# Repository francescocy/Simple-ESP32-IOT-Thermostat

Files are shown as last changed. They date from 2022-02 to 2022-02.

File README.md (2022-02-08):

# Simple-ESP32-IOT-Thermostat

DISCLAIMER - This project was originally developed in Italian, I'll try to translate as much of it as possible in English; code and comments are English-only already.

PLEASE USE THE LATEST VERSION OF THE .ino FILE! New features and bugfixes are listed as comments at the beggining of each .ino file.

INTRODUCTION

This project was born out of a simple idea: replacing our old and clunky living room thermostat with a modern IOT one, while keeping it simple, DIY and fully open-source. I didn't want to rely on a home assistant or a dodgy app-controlled pre-built thermostat, as they tend to have inexistent long-term support and come with too many options.

DEVELOPMENT CHOICES

Main objective is to end up with an extremely simple LCD interface in the living room, with remote control possible using an HTML page.
The unit must fit within the original thermostat's volume and mimick its look; a 3D printed faceplate will be designed for this.
The LCD must show and allow editing of all key paramenters (set temperature, current temperature, furnace status...)
Advanced options can be added later and will be controlled through HTML.

HARDWARE:

NodeMCU-32s

Dallas DS18B20 digital temperature sensor

ST7735 SPI LCD 1.8" 128x160 pixel

10A 220V relay, with optocoupler, 5V powered, 3.3V and 5V signal input

HiLink HLK-PM01 Step-Down module, isolated 220V AC -> 5V DC 0.6A

SOFTWARE:

Developed with Arduino IDE 1.8.19

Included libraries: WiFi.h; AsyncTCP.h; ESPAsyncWebServer.h; Wire.h; OneWire.h; DallasTemperature.h; AsyncElegantOTA.h; Arduino_GFX_Library.h

OTA update: https://github.com/ayushsharma82/ElegantOTA

HOW TO USE:

Open the .ino file with Arduino IDE or Atom, edit it to suit your WiFi settings, Board, LCD type/size/rotation, pinout etc... Compile it and upload it!
I hope I'll have time to upload a more extensive guide soon.

Bonus: You can try the pre-compiled .bin file to test the code, but it may not play well with different ESP boards and LCDs/OLEDs; starting from V 1.2.5 you can create a temporary guest wifi network from your router using the baked-in wifi credentials SSID="wifi" PASSWORD="password" (intended for testing only, please download the .ino file, compile it locally with your own wifi credentials and upload it to your esp32).

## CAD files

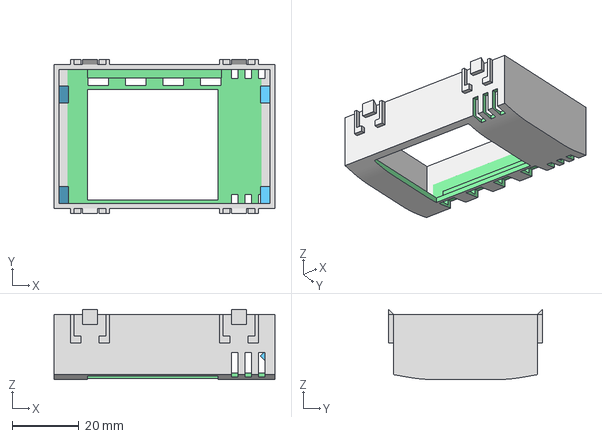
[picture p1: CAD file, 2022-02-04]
Printable 3D faceplate.3mf
66.0 x 46.0 x 21.0 mm

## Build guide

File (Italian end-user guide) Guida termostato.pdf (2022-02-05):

### http://termostato/

SCHEMA DISPLAY TERMOSTATO | PAGINA RAGGIUNGIBILE SULLA LAN O VIA VPN

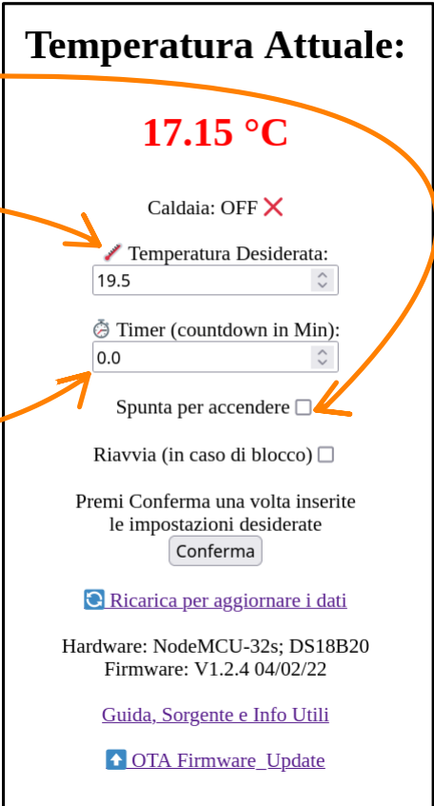
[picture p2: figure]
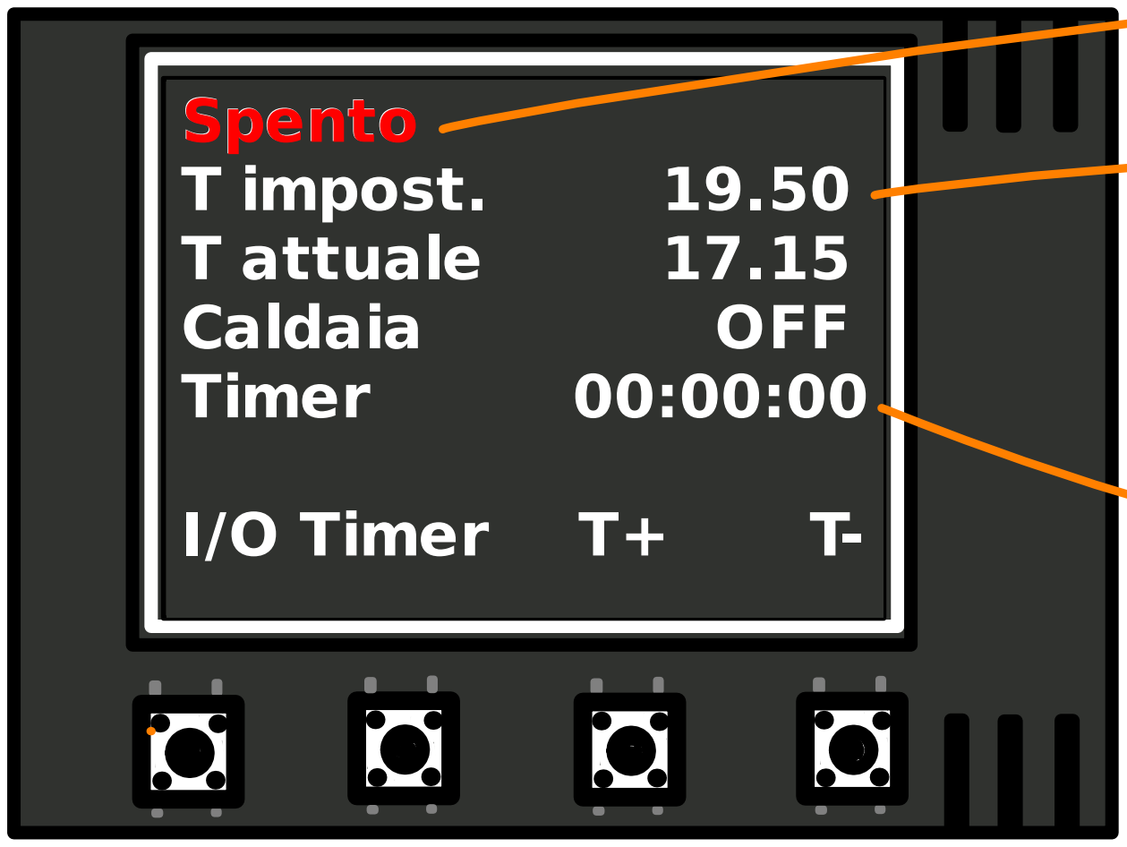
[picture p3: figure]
Spento; T impost.; T attuale; Caldaia; OFF; Timer; I/O Timer

I/O | -> (abilita/disabilita termostato); disabilita il termostato
senza cancellare temperatura e timer attualmente impostati se è già attivo, oppure lo riattiva se non lo è. Una volta attivato, il termostato cercherà di mantenere la temperatura desiderata.

Timer -> Aumenta il contatore di 30' fino a 360 (6h), superate le 6h tornerà a 0 (per impostare tempi più lunghi, usare la pagina HTML). Se il termostato è disabilitato, viene abilitato automaticamente all'inserimento del Timer. Alla fine del countdown, il termostato si disabilita.

T+ | -> Aumenta la temperatura di 0.5⁰C | (fino a un Max di 30⁰C)
T- | -> Riduce la temperatura di 0.5⁰C | (fino a un min di 5⁰C)

INFORMAZIONI UTILI

- Il termostato ha un'isteresi di 0.25⁰C; quando si imposta la temperatura desiderata, la caldaia verrà:
accesa solo se | T Attuale < T Impostata - 0.25⁰C
spenta quando | T Attuale > T Impostata + 0.25⁰C
- La pagina HTML raggiungibile a http://termostato/ è raggiungibile anche all'indirizzo IP (si trova facilmente dalla pagina di management del router della rete di casa)
- I dati presenti sul display sono sempre aggiornati con quelli inviati dall'interfaccia HTML, ma la pagina non si aggiorna automaticamente! Per inviare le impostazioni da remoto, premere il pulsante "Conferma"; per conoscere lo stato attuale del termostato, premere "ricarica per aggiornare i dati"
- In caso di black out, il termostato si riavvierà e tenterà di collegarsi al WiFi automaticamente.
Le impostazioni di default saranno ripristinate: Abilitato in mod. invernale su 15⁰C.
- Se il display non dovesse rispondere/il termostato dovesse comportarsi in maniera erratica, è possibile forzare un riavvio tenendo premuti i tasti I/O + Timer, oppure spuntando l'opportuna casella dalla pagina HTML e poi "Conferma"

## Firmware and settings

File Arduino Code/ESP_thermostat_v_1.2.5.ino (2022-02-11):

/*
 * New in release 1.2.5:
 * Resolved a bug causing the thermostat not to enable when timer is programmed via html
 * Reset timer when user presses I/O button or un-checks field in html page to disable
 * Re-draw menu when pressing I/O or T+ & T- at the same time (useful if stray characters have been printed)
 * menu item drawing moved to "drawMenu" function
 */

#include <WiFi.h>
#include <AsyncTCP.h>
#include <ESPAsyncWebServer.h>
#include <Wire.h>
#include <OneWire.h>
#include <DallasTemperature.h>
#include <AsyncElegantOTA.h>; //this enables OTA updates at IP/update

//setting up GFX for TFT Display starts here
#include <Arduino_GFX_Library.h>
#include "FreeMono8pt7b.h"

/* More dev device declaration: https://github.com/moononournation/Arduino_GFX/wiki/Dev-Device-Declaration */
#if defined(DISPLAY_DEV_KIT)
Arduino_GFX *gfx = create_default_Arduino_GFX();
#else /* !defined(DISPLAY_DEV_KIT) */

/* More data bus class: https://github.com/moononournation/Arduino_GFX/wiki/Data-Bus-Class */
Arduino_DataBus *bus = create_default_Arduino_DataBus();

/* More display class: https://github.com/moononournation/Arduino_GFX/wiki/Display-Class */
Arduino_GFX *gfx = new Arduino_ST7735(bus, TFT_RST, 1 /* rotation */, false /* IPS */);

#endif /* !defined(DISPLAY_DEV_KIT) */
/*******************************************************************************
 * End of Arduino_GFX setting
 ******************************************************************************/
const float tscale = 0.88; /*time scaling to adjust for clock inaccuracy; won't be perfect,
but saves us from using NTP or an RTC (lower values make the timer run faster)*/
float   timer = 0;  //time in min
float   tcnt = 0;   //actual time counter
int     hrrem = 0;  //H remaining
int     minrem = 0; //Min remaining
int     secrem = 0; //Sec remaining
#define  maxtemp 30 //Max allowed temperature in input field
#define  mintemp 5  //min allowed temperature in input field
float   settemp = 15;
#define temp_offset -3.6 //sensor offset in Celsius

// PWM or DAC specs for BL control
#define TFT_BL     25
#define maxdutycycle 255
#define mindutycycle 210
#define BL_cntDownMax 50
int     dutycycle = 255;
int     BTN_Press = 0;
int     BL_cntDown = BL_cntDownMax;

//Hardware Buttons
int del = 0; //general delay to run at beginning of loop
#define btndelays 2 //avoids double press
#define btndelayl 10 //delay for longer operations, like resetting timer
#define BTN1      13 //on/off
#define BTN2      14 //timer
#define BTN3      16 //temp +
#define BTN4      17 //temp -

const char* ssid = "MINOU";   //replace with your SSID
const char* password = "thispasswordissaferthantheprevious"; //password

String input_field = "15.0";
String last_temperature;
String enable_trigger = "checked";
String input_field2 = "true";
String input_field2prev = "true"; //Support variable to enable automatic Timer enable/disable logic
String input_field3 = "0.0";
String reboot = "";
String input_field4 = "false";
String anim = "+";
String heater = "";
String hostname = "Termostato";
String firmware = "V1.2.5 08/02/22";
int caldaia = 0;

const char index_html[] PROGMEM = R"rawliteral(
<!DOCTYPE HTML><html><head>
  <title>termostato</title>
  <meta name="viewport" content="width=device-width, initial-scale=1">

  <style>
    html {font-family: Times New Roman; display: inline-block; text-align: center;}
    h2 {font-size: 2.0rem;}
    h3 {font-size: 2.0rem; color: #FF0000;}
  </style>
  
  </head><body>
  <h2>Temperatura Attuale:</h2> 
  <h3>%TEMPERATURE% &deg;C</h3>
  <a>Caldaia: %HEATER%</a><br><br>
  <form action="/get">
    &#127777;&#65039; Temperatura Desiderata:<br><input type="number" step="0.5" name="threshold_input" value="%THRESHOLD%" required><br><br>
    &#9201;&#65039; Timer (countdown in Min):<br><input type="number" step="0.1" name="timer_input" value="%TIMER%" required><br><br>
    Spunta per accendere<input type="checkbox" name="enable_triggerInput" value="true" %ENABLE_TRIGGER_INPUT%><br><br>
    Riavvia (in caso di blocco)<input type="checkbox" name="reboot_input" value="true" %ENABLE_REBOOT%><br><br>
    Premi Conferma una volta inserite<br>le impostazioni desiderate<br>
    <input type="submit" value="Conferma">
  </form><br>
  <a href='/'>&#128260; Ricarica per aggiornare i dati</a><br><br>
  <a>Hardware: NodeMCU-32s; DS18B20</a><br>
  <a>Firmware: %FW%</a><br><br>
  <a href='https://cloud.lilik.it/s/y3zB48q2M7eSgWN'>&#128209;Guida al termostato</a><br><br>
  <a href='https://github.com/francescocy/Simple-ESP32-IOT-Thermostat'>&#128049;GitHub&#128025;</a><br><br>
  <a href='/update'>&#11014;&#65039; OTA Firmware_Update &#11014;&#65039;</a>
</body></html>)rawliteral";

void notFound(AsyncWebServerRequest *request) {
  request->send(404, "text/plain", "Not found");
}

void(* resetFunc) (void) = 0; // create a standard reset function

void drawMenu() {
    // Fill LCD with black and Print main menu elements
    gfx->fillScreen(BLACK);
    gfx->setTextColor(WHITE, BLACK);
    gfx->setCursor(0, 30);
    gfx->println("T Impost.");
    gfx->setCursor(0, 50);
    gfx->println("T Attuale");
    gfx->setCursor(0, 70);
    gfx->println("Caldaia");
    gfx->setCursor(0, 90);
    gfx->println("Timer");
    //show button layout on screen
    gfx->setCursor(0, 125);
    gfx->println("I/0 Timer T+  T-");
}

AsyncWebServer server(80);

String processor(const String& var){

  if(var == "TEMPERATURE"){
    return last_temperature;
  }
  else if(var == "THRESHOLD"){
    return String(settemp, 1);
  }
  else if(var == "ENABLE_TRIGGER_INPUT"){
    return enable_trigger;
  }
  else if(var == "TIMER"){
    return String((timer), 1);
  }
  else if(var == "ENABLE_REBOOT"){
    return reboot;
  }
  else if(var == "FW"){
    return firmware;
  }
  else if(var == "HEATER"){
    return heater;
  }
//starting here we add extra variables to monitor!
  else if(var == "BLCNTD"){
    return String((BL_cntDown), 3);
  }
  else if(var == "TCNT"){
    return String((tcnt), 3);
  }
  else if(var == "DEL"){
    return String((del), 3);
  }
//and they end here
  return String();
}

bool triggerActive = false;

const char* input_paramter1 = "threshold_input";
const char* input_paramter2 = "enable_triggerInput";
const char* input_paramter3 = "timer_input";
const char* input_paramter4 = "reboot_input";

unsigned long previousMillis = 0;     
const long interval = 5;    


const int ESP_output = 12;
const int oneWireBus = 32;     
OneWire oneWire(oneWireBus);
DallasTemperature sensors(&oneWire);

//Create a function to check when WiFi drops using events and automatically re-connect
void Wifi_disconnected(WiFiEvent_t event, WiFiEventInfo_t info){
  WiFi.begin(ssid, password);
}

void setup() {
//Relay output pin
pinMode(ESP_output, OUTPUT);
digitalWrite(ESP_output, LOW);

//Hardware Buttons setup
pinMode(BTN1, INPUT_PULLUP);
digitalWrite(BTN1, HIGH);
pinMode(BTN2, INPUT_PULLUP);
digitalWrite(BTN2, HIGH);
pinMode(BTN3, INPUT_PULLUP);
digitalWrite(BTN3, HIGH);
pinMode(BTN4, INPUT_PULLUP);
digitalWrite(BTN4, HIGH);

//Brightness DAC control setup
#if defined(LCD_PWR_PIN)
pinMode(LCD_PWR_PIN, OUTPUT);    // sets the pin as output
digitalWrite(LCD_PWR_PIN, HIGH); // power on
#endif
pinMode(TFT_BL, OUTPUT);
//digitalWrite(TFT_BL, HIGH);
dacWrite(TFT_BL,dutycycle);
  
//initializing TFT LCD
gfx->begin();
//Filling with black background
gfx->fillScreen(BLACK);

//setting the font & printing boot-up welcome message
gfx->setFont(&FreeMono8pt7b);

    gfx->setTextColor(WHITE, BLACK);
    gfx->setCursor(0, 20);
    gfx->println("Ciao!");
    gfx->setCursor(0, 40);
    gfx->println("Sono il tuo");
    gfx->setCursor(0, 55);
    gfx->println("termostato IOT");
    gfx->setCursor(0, 75);
    gfx->println("F.W.Version:");
    gfx->setCursor(0, 90);
    gfx->setTextColor(GREEN, BLACK);
    gfx->println(firmware);
    gfx->setCursor(0, 120);
    gfx->setTextColor(WHITE, BLACK);
    gfx->println("FOSS by Barb");

    delay(1000); // wait 1 sec
    gfx->fillScreen(BLACK);
//End of TFT LCD initialization
  
//Starting from now, a wifi connection is established and its parameters are printed on the LCD
  WiFi.mode(WIFI_STA);
  WiFi.config(INADDR_NONE, INADDR_NONE, INADDR_NONE, INADDR_NONE);
  WiFi.setHostname(hostname.c_str()); //define hostname
  WiFi.onEvent(Wifi_disconnected, SYSTEM_EVENT_STA_DISCONNECTED); //call on wifi reconnection if disconnected
  WiFi.begin(ssid, password);
  if (WiFi.waitForConnectResult() != WL_CONNECTED) {
    gfx->println("Connecting...");
    return;
  }
  delay(1000); // 1sec

//Print main menu elements only once, this helps reduce flicker
 drawMenu();
  

sensors.begin();
  
  server.on("/", HTTP_GET, [](AsyncWebServerRequest *request){
    request->send_P(200, "text/html", index_html, processor);
  });

  server.on("/get", HTTP_GET, [] (AsyncWebServerRequest *request) {
    if (request->hasParam(input_paramter1)) {
      input_field = request->getParam(input_paramter1)->value();
      settemp = input_field.toFloat();
    }
    if (request->hasParam(input_paramter3)) {
      input_field = request->getParam(input_paramter3)->value();
      timer = input_field.toFloat();
      //Enable thermostat when timer is started
      enable_trigger = "checked";
      triggerActive = true;
    }
      if (request->hasParam(input_paramter2)) {
        input_field2 = request->getParam(input_paramter2)->value();
        enable_trigger = "checked";
        triggerActive = true;
      }
      else {
        input_field2 = "false";
        enable_trigger = "";
        triggerActive = false;
      }
      if (request->hasParam(input_paramter4)) {
        input_field4 = request->getParam(input_paramter4)->value();
        reboot = "checked";
      }
      else {
        reboot = "";
      }
    request->send_P(200, "text/html", index_html, processor); // Re-send main page, with data!
    //request->send(200, "text/html", "<h1 style="font-size: 2rem">href='/'>Return to Home Page</h1>");  //requires manual click, but font is larger
  });
  server.onNotFound(notFound);
  AsyncElegantOTA.begin(&server); //enables OTA updates from the browser
  server.begin();
}

void loop() {

//generalised delay logic, makes it easier to count per cycle without interrupting everything every time
delay(del + 45);
if (del > 0) {
  del--;
}
else {
  del = 0;
}

//soft reset
if (reboot == "checked") {
  resetFunc();
}
// Reset if I/O & Timer are pressed at the same time
else if (digitalRead(BTN1) == LOW && digitalRead(BTN2) == LOW) {
  resetFunc();
}
// Re-draw menu items if T+ & T- are pressed at the same time
else if (digitalRead(BTN3) == LOW && digitalRead(BTN4) == LOW) {
  // Fill LCD with black and re-Print main menu elements only once, in case they got garbled
    drawMenu();
}

//safety limits to avoid over/under-heating
  if(settemp<mintemp){
    settemp=maxtemp;
  }
  if(settemp>maxtemp){
    settemp=mintemp;
  }
//Hardware Buttons Input Logic
  if(digitalRead(BTN1) == LOW && input_field2 == "false" && enable_trigger == "" && del == 0){
    triggerActive = true;
    input_field2 = "true";
    enable_trigger = "checked";
    BTN_Press = 1;
    del = btndelays;
    drawMenu();
  }
  else if(digitalRead(BTN1) == LOW && input_field2 == "true" && enable_trigger == "checked" && del == 0){
    triggerActive = false;
    input_field2 = "false";
    enable_trigger = "";
    BTN_Press = 1;
    del = btndelays;
    tcnt = 1; // Reset timer when disabling
    drawMenu();
  }

  if(digitalRead(BTN2) == LOW && timer < 361 && del == 0){
    //timer = timer+30*120*tscale; //scaling should be 120, as we count down in 500ms, but for some reason it's off by 5%
    timer = timer + 30;
    BTN_Press = 1;
    del = btndelays;
  }
  
  else if(digitalRead(BTN2) == LOW && timer >= 361 && del == 0){
    timer = 0;
    BTN_Press = 1;
    del = btndelays;
  }
  // New auto-disabling timer logic, prevents automatic disabling on every cycle, only disables when enable option is unchecked
  if (input_field2 != input_field2prev && input_field2 != "true") {
    timer = 1/(120*tscale); // Reset timer when disabling
  }
  input_field2prev = input_field2;
tcnt = timer*120*tscale;

//Beginning of Timer countdown logic
  if (tcnt == 0) {
    // Do nothing, default condition
  }
  else if (tcnt == 1){
    //End of countdown, disable thermostat, turn gas furnace off
    digitalWrite(ESP_output, LOW);
    triggerActive = false;
    input_field2 = "false";
    enable_trigger = "";
    tcnt = 0;
    //gfx->fillScreen(BLACK);
  }
  else if (tcnt > 0 && digitalRead(BTN2) == HIGH && del == 0){
    //added commands to enable thermostat when timer is active to simplify user input
    triggerActive = true;
    input_field2 = "true";
    enable_trigger = "checked";
    tcnt--;
  }
  else if (tcnt < 0){
    digitalWrite(ESP_output, LOW);
    triggerActive = false;
    input_field2 = "false";
    enable_trigger = "";
    tcnt = 0;
  }

//Computing time in minutes
timer = tcnt/(120*tscale);

//Increase and decrease temperature with hardware buttons
  if(digitalRead(BTN3) == LOW && del == 0){
    settemp=settemp+.5;
    BTN_Press = 1;
    del = btndelays;
  }
  if(digitalRead(BTN4) == LOW && del == 0){
    settemp=settemp-.5;
    BTN_Press = 1;
    del = btndelays;
  }
  input_field.concat(settemp); //Pass set temperature value to HTML string
  
//BL dimming logic
  if (BTN_Press == 1){
    BL_cntDown = BL_cntDownMax;
  }
  while (dutycycle < maxdutycycle && BL_cntDown == BL_cntDownMax){
    dutycycle++;
    dacWrite(25,dutycycle);
    delay(10);
  }

  if (BTN_Press == 0 && BL_cntDown > 0){
    BL_cntDown--;
  }
  while (dutycycle > mindutycycle && BL_cntDown == 1){
    dutycycle--;
    dacWrite(25,dutycycle);
    delay(10);
  }
  BTN_Press = 0;
//End of dimming logic
  
//Sensor integration logic and visual interface
//Static elements are printed only once during setup and are not repeated here, this helps reduce flicker
  unsigned long currentMillis = millis();
  if (currentMillis - previousMillis >= interval) {
    previousMillis = currentMillis;
    sensors.requestTemperatures();
    // Temperature in Celsius degrees 
    float temperature = sensors.getTempCByIndex(0)+(temp_offset);
    gfx->setTextColor(WHITE, BLACK);
    gfx->setCursor(0, 10);
    //gfx->println("Stato Riscaldamento:");
    if (input_field2 == "true"){
      gfx->setTextColor(GREEN, BLACK);
      gfx->println("Mod. Invernale");
    }
    else {
      gfx->setTextColor(BLUE, BLACK);
      gfx->println("Spento        ");
    }
    gfx->setTextColor(WHITE, BLACK);
    //gfx->setCursor(0, 30);
    //gfx->println("T Impost.");
    gfx->setCursor(110, 30);
    //gfx->println(input_field.toFloat());
    gfx->println(settemp);
    //gfx->setCursor(0, 50);
    //gfx->println("T Attuale");
    gfx->setCursor(110, 50);
    gfx->println(temperature);
    //gfx->setCursor(0, 70);
    //gfx->println("Caldaia");
    gfx->setCursor(110, 70);
    if (caldaia == 1 && input_field2 == "true"){
      heater = "ON &#128293;";
      gfx->setTextColor(GREEN, BLACK);
      gfx->println("ON ");
    }
    else {
      heater = "OFF &#10060;";
      gfx->setTextColor(BLUE, BLACK);
      gfx->println("OFF");
    }
    gfx->setTextColor(WHITE, BLACK);
    //gfx->setCursor(0, 90);
    //gfx->println("Timer");
    gfx->setCursor(60, 90);
    gfx->println("             ");

    //computing remaining time
    if (timer > 0) {
      gfx->setTextColor(GREEN, BLACK);
    }
      hrrem = timer/(60); //make integer
      minrem = (timer-hrrem*60);
      secrem = 60*(timer-hrrem*60-minrem);
    
    //displaying remaining time, since v1.2.3 single digits are shifted by 9 pixels to align right

    gfx->setCursor(90, 90); gfx->println("  ");
    if (hrrem < 10) {
      gfx->setCursor(99, 90); gfx->println(hrrem);
    }
    else {
      gfx->setCursor(90, 90); gfx->println(hrrem);
    }
    
    gfx->setCursor(108, 90); gfx->println(":");
    gfx->setCursor(115, 90); gfx->println("  ");
    if (minrem < 10) {
      gfx->setCursor(124, 90); gfx->println(minrem);
    }
    else {
      gfx->setCursor(115, 90); gfx->println(minrem);
    }
    
    gfx->setCursor(133, 90); gfx->println(":");
    gfx->setCursor(140, 90); gfx->println("  ");
    if (secrem < 10) {
      gfx->setCursor(149, 90); gfx->println(secrem);
    }
    else {
      gfx->setCursor(140, 90); gfx->println(secrem);
    }
    
//Pass Current Temp to HTML string processor
    last_temperature = String(temperature);
    
//Thermostat control logic
    if(temperature > settemp+0.25){
      triggerActive = true;
      caldaia = 0;
      digitalWrite(ESP_output, LOW);
    }
    else if((temperature < settemp-0.25) && input_field2 == "true" && triggerActive) {
      triggerActive = false;
      caldaia = 1;
      digitalWrite(ESP_output, HIGH);
    }
    if(input_field2 != "true") {
      digitalWrite(ESP_output, LOW);
      triggerActive = false;
    }
  }
}

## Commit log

2022-02-04 Add files via upload
    3D printable faceplate with 4 buttons, compatible with Bticino livinglight
    [Printable 3D faceplate.3mf]
2022-02-11 Fixed missing () in drawmenu
    [ESP_thermostat_v_1.2.5.ino]
